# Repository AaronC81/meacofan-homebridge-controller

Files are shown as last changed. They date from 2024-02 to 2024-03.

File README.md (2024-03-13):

# Meacofan HomeBridge Controller

This project connects a [MeacoFan 1056](https://www.meaco.com/products/meacofan-1056-air-circulator)
desk fan to HomeKit using [Homebridge](https://homebridge.io/), enabling it to be controlled using
your iOS device or Siri.

The PCB blasts the same IR commands as the fan's real remote control, accepting commands over I2C so
that it can be controlled from a Raspberry Pi.

> [!WARNING]
> This is quite rough around the edges. I wouldn't recommend building one of these yourself!

## PCB

The PCB is a KiCad project in `hardware/pcb`. (The BOM is hopefully self-explanatory from the
schematic!)

Once assembled, the on-board ISP port can be used to flash the ATtiny85. You'll also need to set
appropriate fuses to use the internal 8 MHz clock, which the software relies on. The AVRDUDE flags
for this are:

```
-U lfuse:w:0xe2:m -U hfuse:w:0xdf:m -U efuse:w:0xff:m
```

(Note that, until the clock is increased with these fuses, you may need to slow down ISP
communication speed: `-B 125kHz`)

## Homebridge Plugin

`homebridge-plugin` contains a Homebridge accessory plugin which implements the
[`Fan`](https://developers.homebridge.io/#/service/Fan) service. This sends I2C commands to the PCB
to match the desired speed set through HomeKit. (HomeKit only supports 0%-100% speeds, so these
are mapped onto the fan's 1-12 speed settings.)

You will need the `i2c-tools` package installed to provide the `i2ctransfer` command-line tool.
Make sure that I2C is enabled in your `raspi-config` too. If everything is working OK, the device
should appear at address 0x40 in `i2cdetect`.

## Software

The software is written as a PlatformIO project targeting the ATtiny85, using the Arduino framework.

### Communication

The ATtiny85 acts as a bit-banged I2C peripheral on address 0x40. Only one operation is supported,
a single-byte write where the byte is in the following format:

```
  .--------------- checksum - number of 1s in rest of packet
.-'-.
c c c 1 s s s s
        '--.--'
           '------ new desired speed (0-12), 0 means off
```

These packets are designed to be idempotent, so your host should probably send these multiple times
to account for the sloppy I2C bit-banging.

### IR Commands

The fan operates with NEC-format IR codes at address 0x80. The individual commands are documented
below: 

| Purpose | Command | Raw |
| --- | --- | --- |
| Power | 0x92 | 0x6D927F80 |
| Vertical oscillation | 0x8A | 0x758A7F80 |
| Horizontal oscillation | 0x87 | 0x78877F80 |
| Eco | 0x81 | 0x7E817F80 |
| Pre-on | 0x82 | 0x7D827F80 |
| Pre-off | 0x83 | 0x7C837F80 |
| Light | 0x9E | 0x619E7F80 |
| Speed up | 0x89 | 0x76897F80 |
| Speed down | 0x9F | 0x609F7F80 |

## Enclosure

There's a very rough 3D printed enclosure which keeps the IR LED aimed in `hardware/case`.

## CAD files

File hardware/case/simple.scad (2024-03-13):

$fn=50;

INFINITY = 99999;
INFINITY_DIV2 = INFINITY / 2;

board_depth = 1.6;
board_width = 36;
board_height = 32;
corner_radius = 4.06;

module board_outline() {
    translate([corner_radius, corner_radius])
    minkowski() {
        circle(r=corner_radius);
        square([
            board_width - corner_radius * 2,
            board_height - corner_radius * 2,
        ]);
    }
}

module mounting_post() {
    m3_screw_hole_inner_diameter = 2.6;
    post_diameter = m3_screw_hole_inner_diameter + 3;
    
    difference() {
        circle(d=post_diameter);
        circle(d=m3_screw_hole_inner_diameter);
    }
}

module case() {
    case_border_width = 2;
    case_bottom_depth = 2;
    
    case_mounting_height = 7;
    
    module case_outline() {
        offset(case_border_width)
        board_outline();
    }
    module case_border() {
        difference() {
            case_outline();
            board_outline();
        }
    }

    // Base
    linear_extrude(case_bottom_depth)
    case_outline();
    
    translate([0, 0, case_bottom_depth]) {
        // Border around board
        linear_extrude(case_mounting_height)
        case_border();
        
        // Mounting posts
        linear_extrude(case_mounting_height - board_depth) {
            for (x = [corner_radius, board_width - corner_radius]) {
                for (y = [corner_radius, board_height - corner_radius]) {
                    translate([x, y])
                    mounting_post();
                }
            }
        }
    }
    
    // Raise one side of the border up higher, and cut an angled "chute" in it for the LED
    led_support_height = 70;
    led_diameter = 5;
    led_chute_border = 1.5;
    led_chute_length = 4;
    led_chute_angle = 120;
    module led_chute(add_length=0) {
        rotate([led_chute_angle, 0, 0])
        linear_extrude(led_chute_length + add_length)
        difference() {
            circle(d=led_diameter + led_chute_border);
            circle(d=led_diameter);
        }
    }
    
    translate([0, 0, case_bottom_depth + case_mounting_height])
    union() {
        difference() {
            linear_extrude(led_support_height)
            intersection() {
                case_border();

                translate([-INFINITY_DIV2, -case_border_width, 0])
                square([INFINITY, 10]);
            }
            
            translate([board_width / 2, led_chute_length/2.5, led_support_height - led_diameter])
            hull() led_chute(INFINITY);
        }
        
        translate([board_width / 2, led_chute_length/2.5, led_support_height - led_diameter])
        led_chute();
    }
}

case();

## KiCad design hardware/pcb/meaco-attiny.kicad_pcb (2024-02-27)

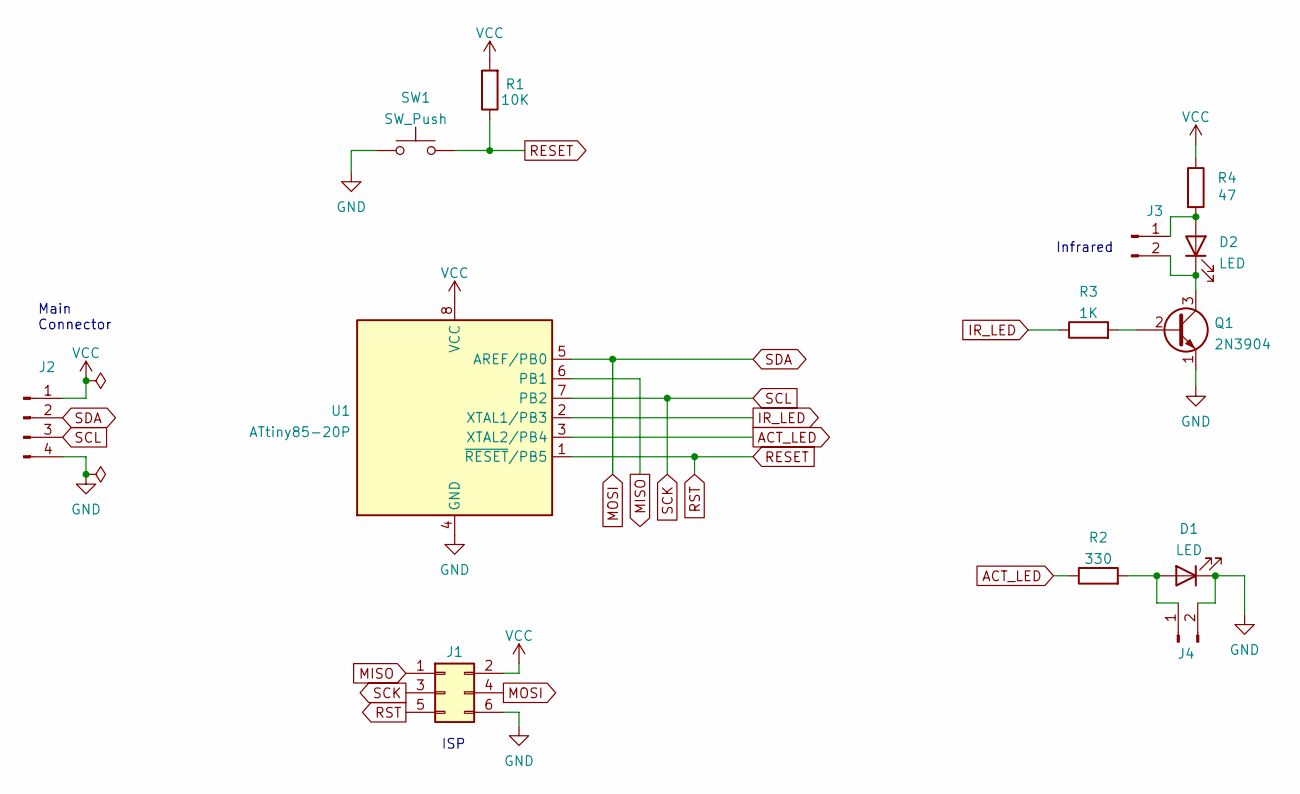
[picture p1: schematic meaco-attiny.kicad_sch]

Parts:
D1, D2: LED; LED_D5.0mm
J1: Conn_02x03_Odd_Even; PinHeader_2x03_P2.54mm_Vertical
J2: Conn_01x04_Male; PinHeader_1x04_P2.54mm_Vertical
J3, J4: Conn_01x02_Male; PinHeader_1x02_P2.54mm_Vertical
Q1: 2N3904; TO-92_Inline
R1: 10K; R_0603_1608Metric
R2: 330; R_0603_1608Metric
R3: 1K; R_0603_1608Metric
R4: 47; R_0603_1608Metric
SW1: SW_Push; SW_PUSH_6mm
U1: ATtiny85-20P; DIP-8_W7.62mm

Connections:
ACT_LED: R2.1, U1.3 (XTAL2/PB4)
GND: D1.1 (K), J1.6, J2.4, J4.2, Q1.1 (E), SW1.1, U1.4 (GND)
IR_LED: R3.1, U1.2 (XTAL1/PB3)
MISO: J1.1, U1.6 (PB1)
MOSI: J1.4, J2.2, U1.5 (AREF/PB0)
unnamed: D1.2 (A), J4.1, R2.2
unnamed: D2.1 (K), J3.2, Q1.3 (C)
unnamed: D2.2 (A), J3.1, R4.2
unnamed: Q1.2 (B), R3.2
RESET: J1.5, R1.1, SW1.2, U1.1 (~RESET/PB5)
SCK: J1.3, J2.3, U1.7 (PB2)
VCC: J1.2, J2.1, R1.2, R4.1, U1.8 (VCC)

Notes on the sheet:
Infrared
ISP
Main Connector

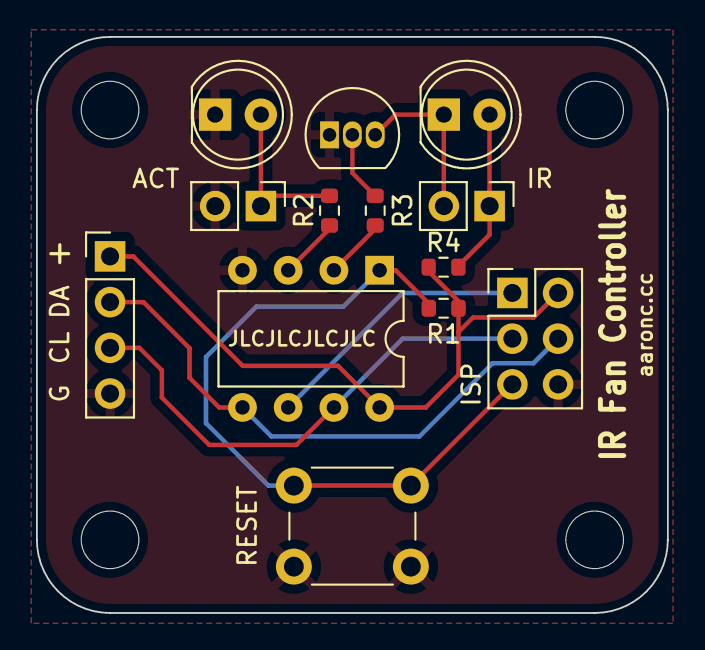
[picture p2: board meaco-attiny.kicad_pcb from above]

Board: 2 copper layers, 35.1 x 32.0 mm, 13 parts (0 on the bottom side), 12 nets.

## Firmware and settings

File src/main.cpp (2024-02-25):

#include <Arduino.h>

#include "nec_ir.hpp"
#include "i2c_peripheral.hpp"
#include "pins.hpp"
#include "fan.hpp"

#include <digitalWriteFast.h>

Fan fan;

void setup() {
    nec_ir::begin();
    i2c_peripheral::begin();

    // Show that we've got power!
    for (int i = 0; i < 3; i++) {
        digitalWrite(I2C_ACTIVITY_PIN, HIGH);
        delay(200);
        digitalWrite(I2C_ACTIVITY_PIN, LOW);
        delay(200);
    }
}

void loop() {
    uint8_t data;
    if (i2c_peripheral::wait_for_byte(&data)) {
        // Packet format:
        //     .--------------- checksum - number of 1s in rest of packet
        //   .-'-.
        //   c c c 1 s s s s
        //           '--.--'
        //              '------ new desired speed (0-12), 0 means off

        // Validate static 1
        if (!(data & 0b00010000))
            return;

        // Validate checksum
        uint8_t provided_checksum = (data & 0b11100000) >> 5;
        uint8_t calculated_checksum = 0;
        calculated_checksum += (data & 0b00010000 ? 1 : 0);
        calculated_checksum += (data & 0b00001000 ? 1 : 0);
        calculated_checksum += (data & 0b00000100 ? 1 : 0);
        calculated_checksum += (data & 0b00000010 ? 1 : 0);
        calculated_checksum += (data & 0b00000001 ? 1 : 0);
        if (calculated_checksum != provided_checksum)
            return;

        uint8_t desired_speed = data & 0x0F;
        if (desired_speed > 12) return;

        bool power; uint8_t up; uint8_t down;
        fan.steps_to_change_speed(desired_speed, &power, &up, &down);

        if (power) {
            fan.toggle_power();
            delay(200);
        }
        for (uint8_t i = 0; i < up; i++) {
            fan.speed_up();
            delay(200);
        }
        for (uint8_t i = 0; i < down; i++) {
            fan.speed_down();
            delay(200);
        }
    }
} 

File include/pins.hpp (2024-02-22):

#pragma once

#define IR_PIN 3

#define I2C_SDA_PIN 0
#define I2C_SCL_PIN 2
#define I2C_ACTIVITY_PIN 4
#define I2C_ADDRESS 0x40

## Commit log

2024-02-18 Initial commit
    ATtiny85 blinky, no external oscillator
    [main.cpp]
2024-02-19 Add IRsend which doesn't work
    I think it's a clock issue
    [main.cpp]
2024-02-21 Add Python class to talk to FT260 for PC<->I2C testing
2024-02-21 Change IR pin
2024-02-21 Terrible I2C bitbang
2024-02-21 Filter on address
2024-02-21 Add a dedicated I2C activity LED pin
2024-02-21 Add fan model with packet control
2024-02-22 Break out I2C handling into a module
2024-02-22 Tidy up I2C code a little bit
2024-02-22 Add a crap timer to bail out of broken transmission
    This does actually work; interrupt-based hardware timers would be way
    better, but this was much easier to implement :P
    [i2c_peripheral.cpp]
2024-02-25 Blink on power on
2024-02-25 Add checksum system to avoid incorrect I2C peripheral message data
    In combination with having the Node app send the packet several times,
    this leads to a vaguely reliable tranmission, I think....?
    [main.cpp]
2024-02-26 Add basic Homebridge plugin for power toggling
    Based on: https://github.com/homebridge/homebridge-examples/tree/latest/accessory-example-typescript
2024-02-27 Add WIP PCB
    [meaco-attiny.kicad_pcb, meaco-attiny.kicad_sch]
2024-02-27 Put swirly pattern on back of PCB
    [meaco-attiny.kicad_pcb]
2024-02-27 JLC! JLC! JLC! JLC!
    [meaco-attiny.kicad_pcb]
2024-03-13 Add basic case
    [simple.scad]
